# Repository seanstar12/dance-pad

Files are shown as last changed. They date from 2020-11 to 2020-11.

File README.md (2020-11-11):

DDR FSR Upgrade (https://youtu.be/kHoUUIsmSGY "DDR FSR Upgrade")

# dance-pad
Code and schematics for Dance Dance Revolution - DDR - FSR sensor upgrade.

# Plan
Use one MEGA238P per arrow to read & convert the 4 FSR values into a pressed/not-pressed signal. 
Use 25 SK6812 LEDs to light up the panel when pressed and show animations when idle.

# Parts
- Arduino-pro-mini clone
- MCP2125 - CAN - interface with Teensy
- Teensy 3.2 - interface with DDR cabinet
- SK6812 - 'Neopixel' LEDs
- FSR - x32 - 4 per tile
- ['Dance Sensor'](https://www.aliexpress.com/item/4000438156295.html) from aliexpress for the TPU shell.
- [FSR](https://www.aliexpress.com/item/4000765691363.html) from aliexpress.

# Why
I have a DDR cabinet, and I am tired of dealing with stuck sensors. This will let me 
calibrate the dance pad on the fly and never have to deal with it again. I've 
wanted to create a CANBus network for a while, and this gives me an excuse to use 
the box of pro-mini clones that I've had for a while now.

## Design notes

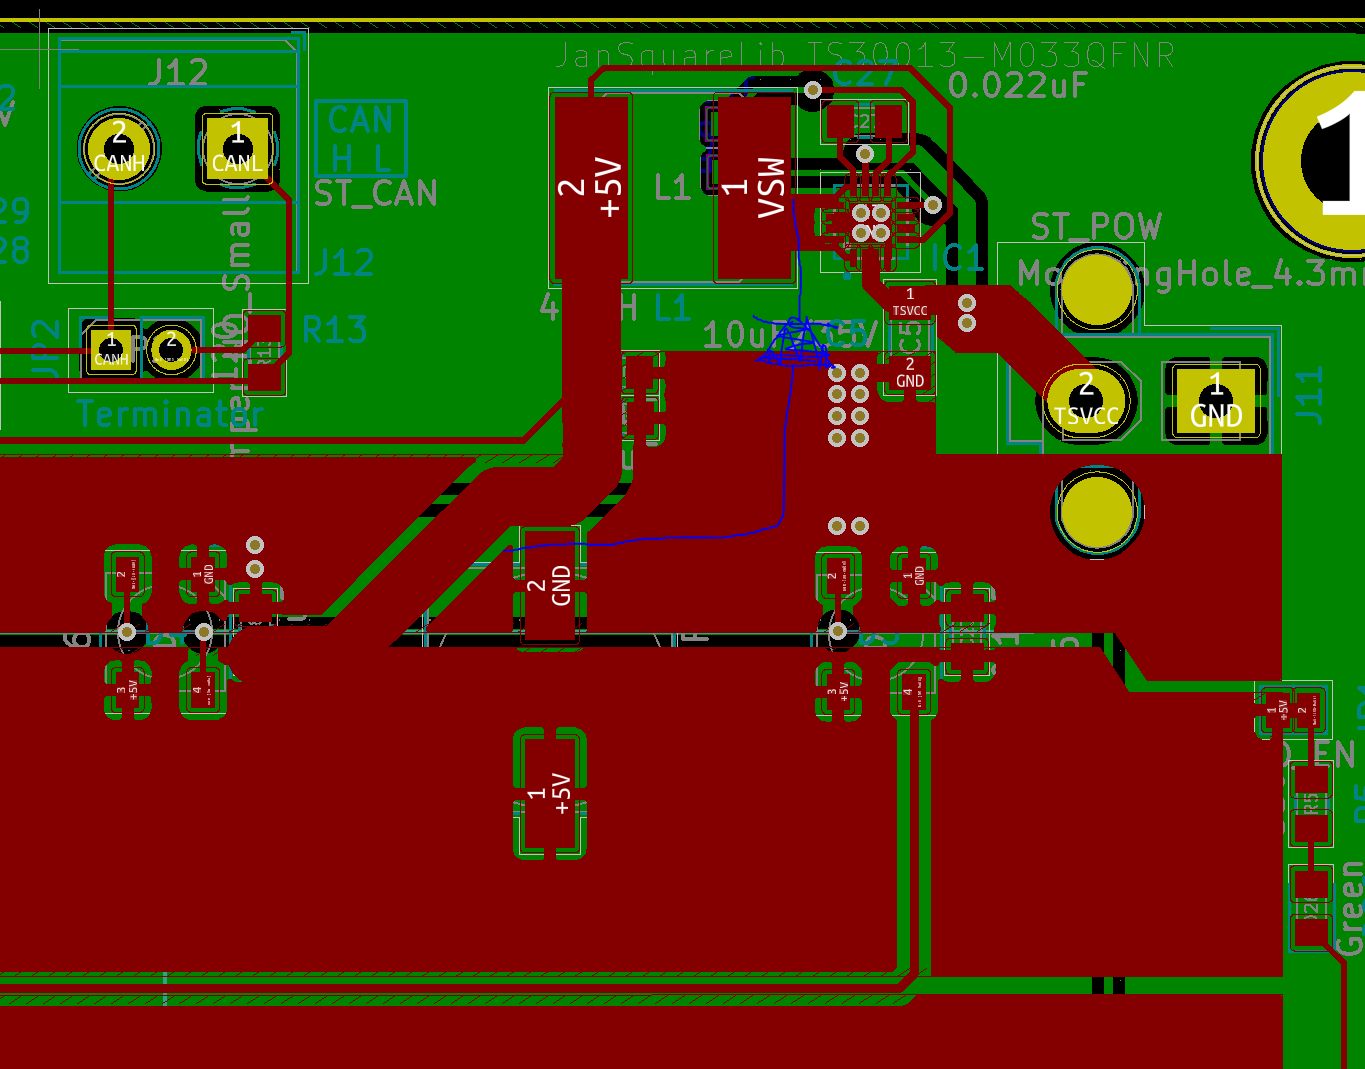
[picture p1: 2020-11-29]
ps_screenshot_diode.PNG

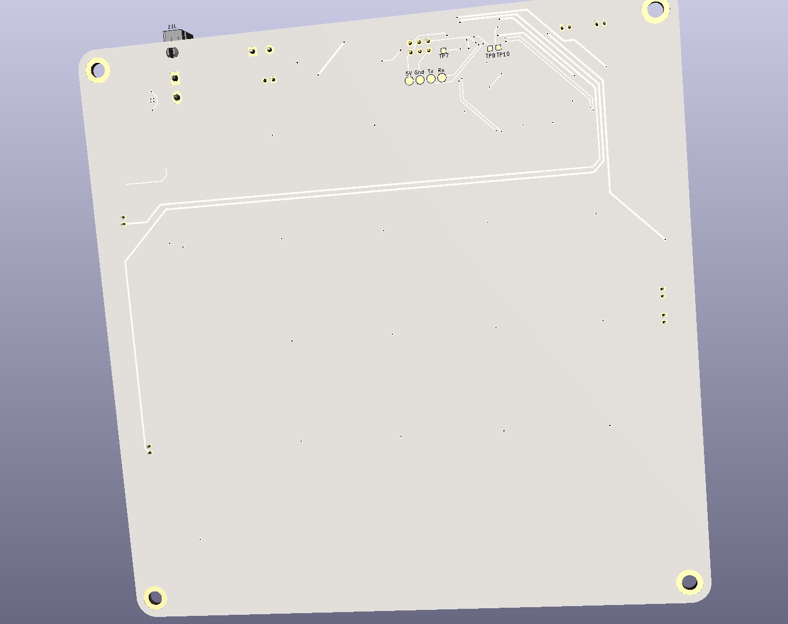
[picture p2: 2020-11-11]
Board_back.PNG

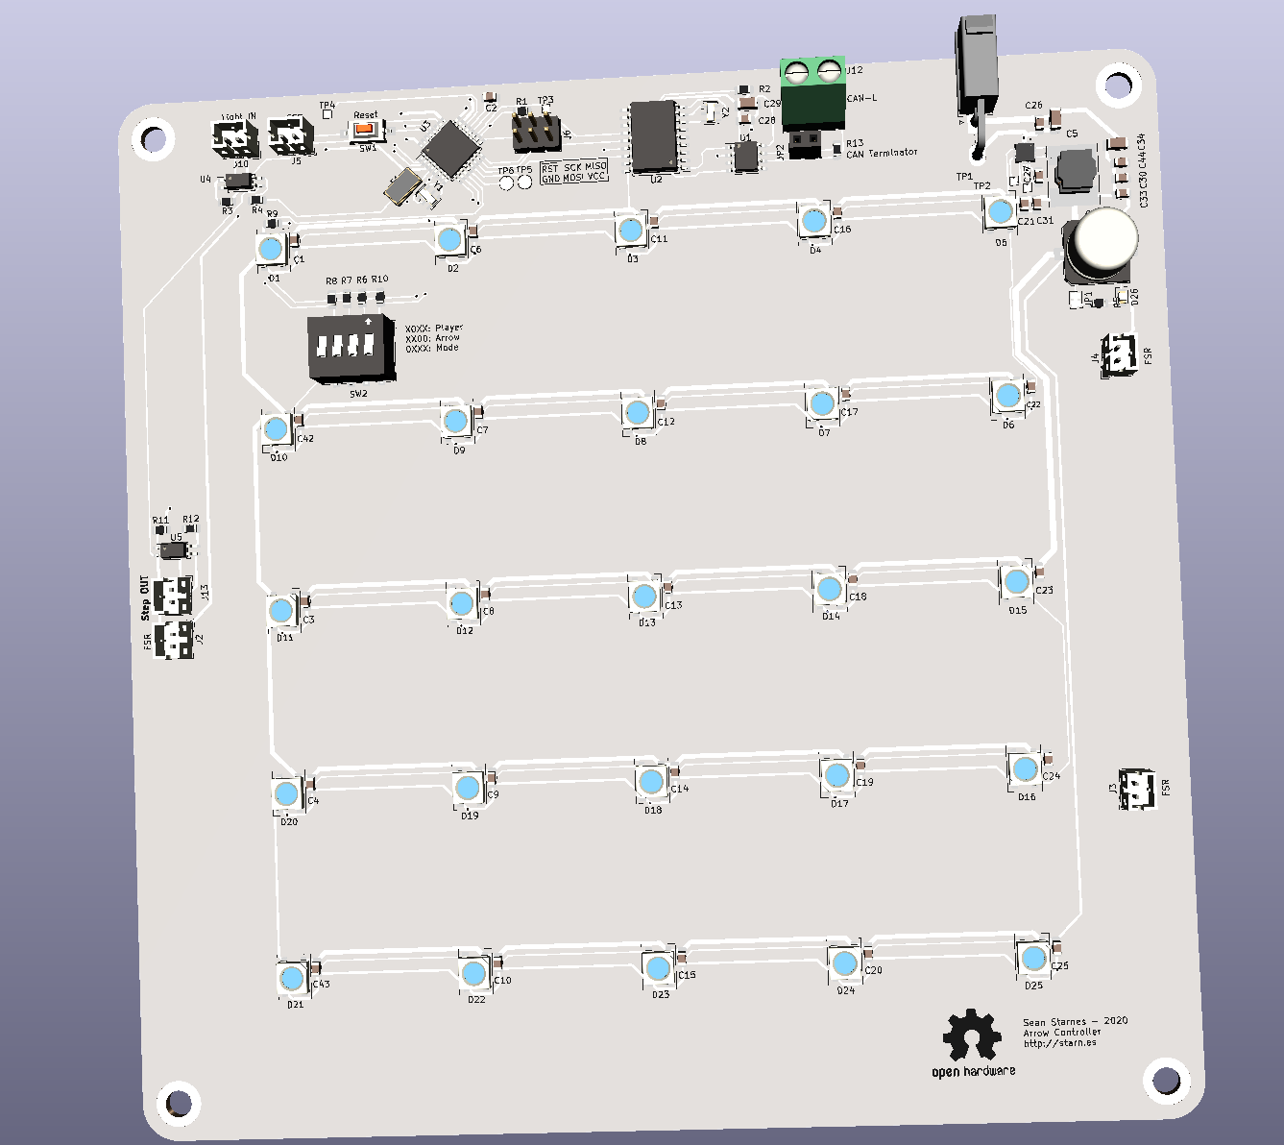
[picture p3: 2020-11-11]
Board_front.PNG

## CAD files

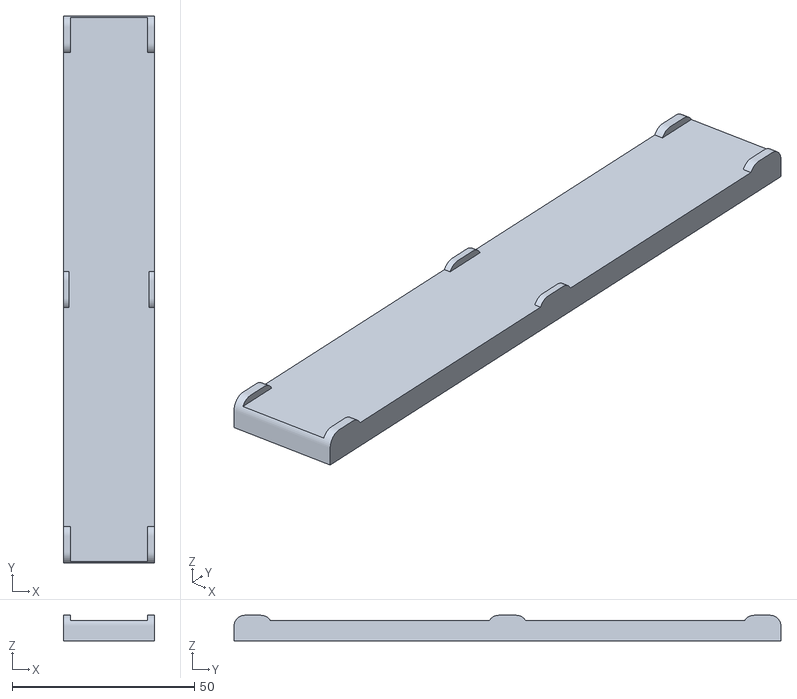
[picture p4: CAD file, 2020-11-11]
3D-prints/ddr_spacer_v3.stl
25.0 x 150.0 x 7.00

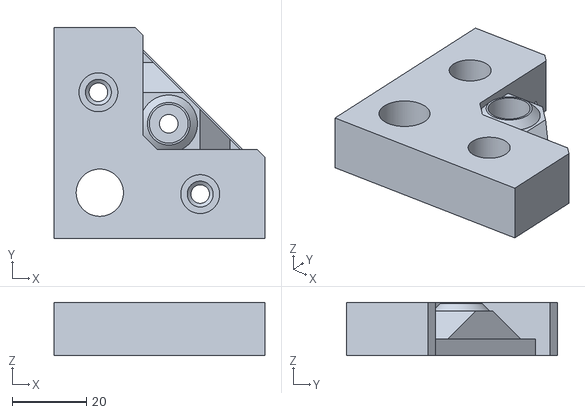
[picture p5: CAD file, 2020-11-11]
3D-prints/ddr_spacer_block.stl
57.0 x 57.0 x 14.4

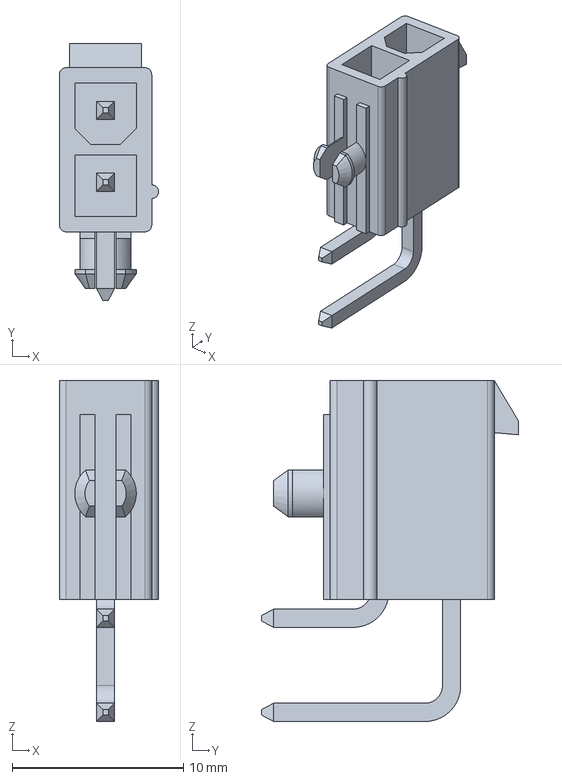
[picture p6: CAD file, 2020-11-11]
kicad/models/26-01-3114_stp/026013114.stp
5.80 x 15.0 x 19.9 mm

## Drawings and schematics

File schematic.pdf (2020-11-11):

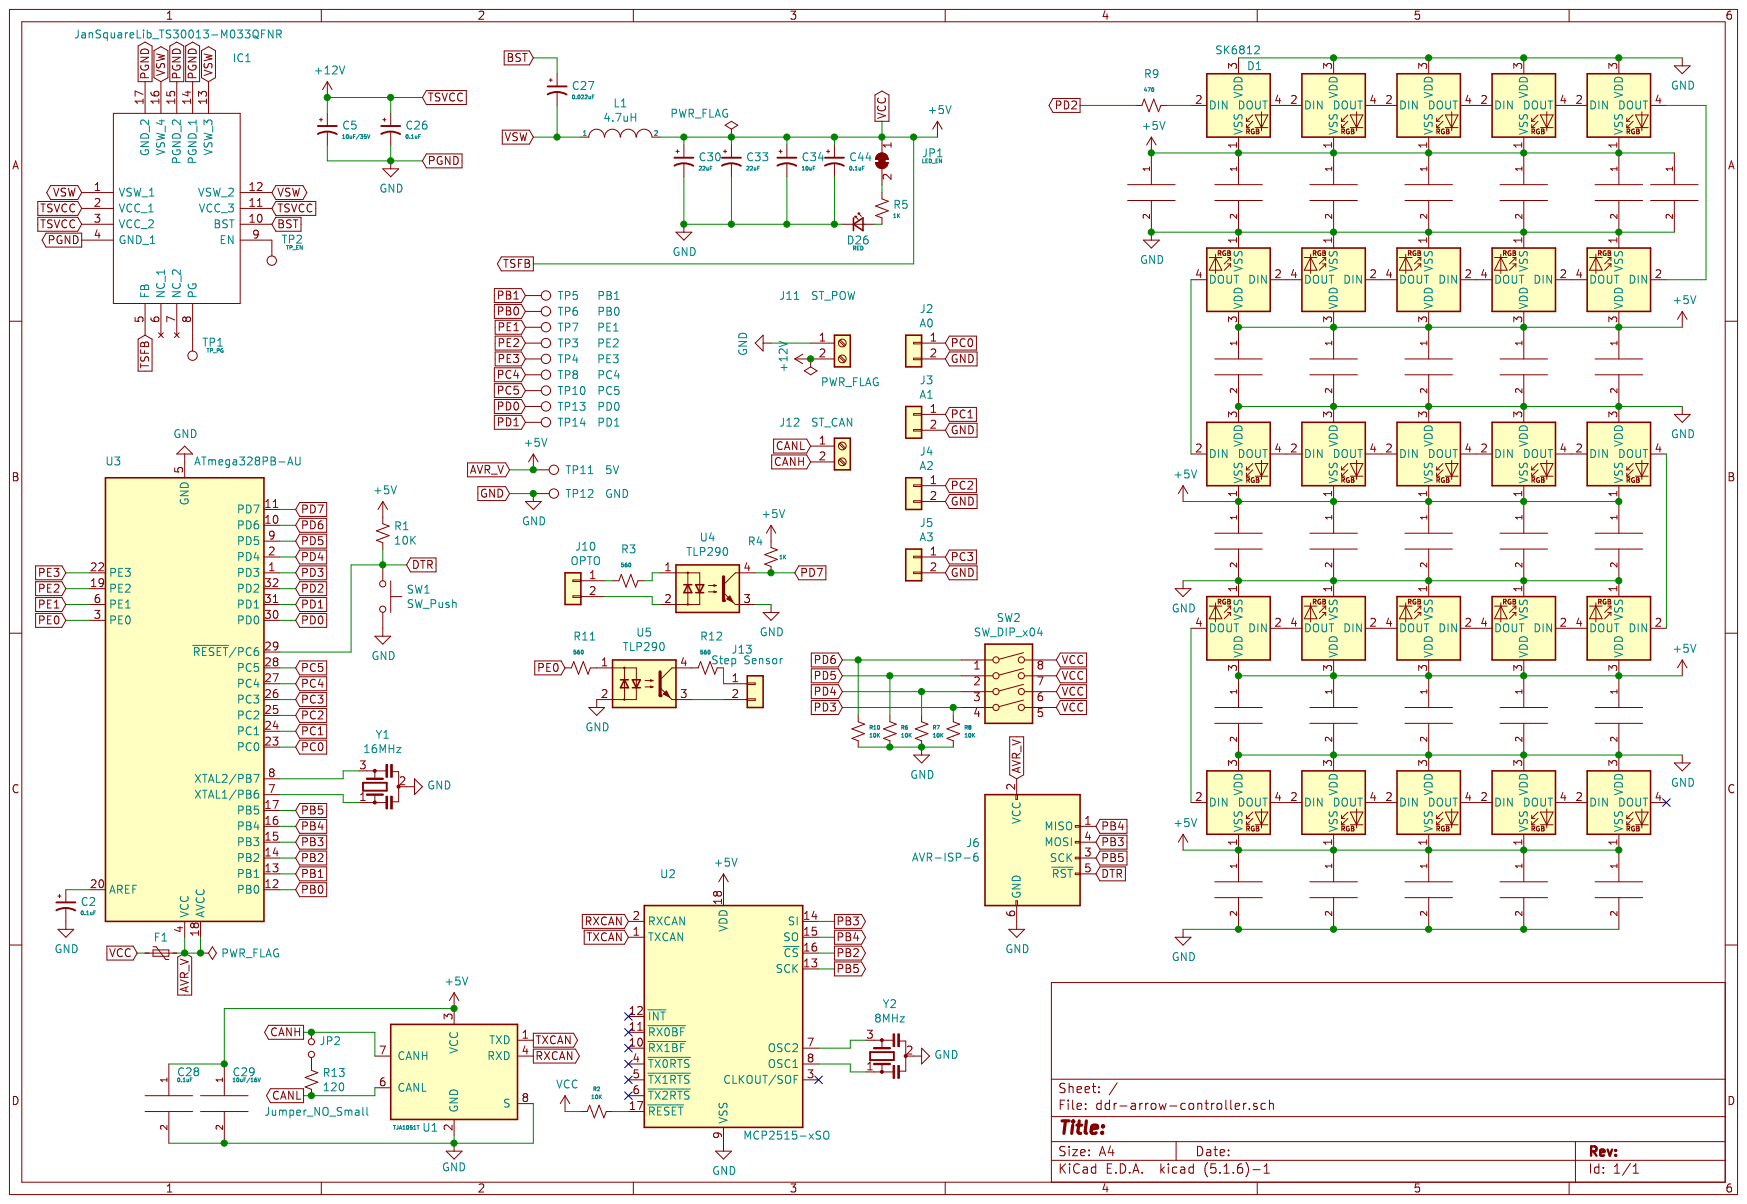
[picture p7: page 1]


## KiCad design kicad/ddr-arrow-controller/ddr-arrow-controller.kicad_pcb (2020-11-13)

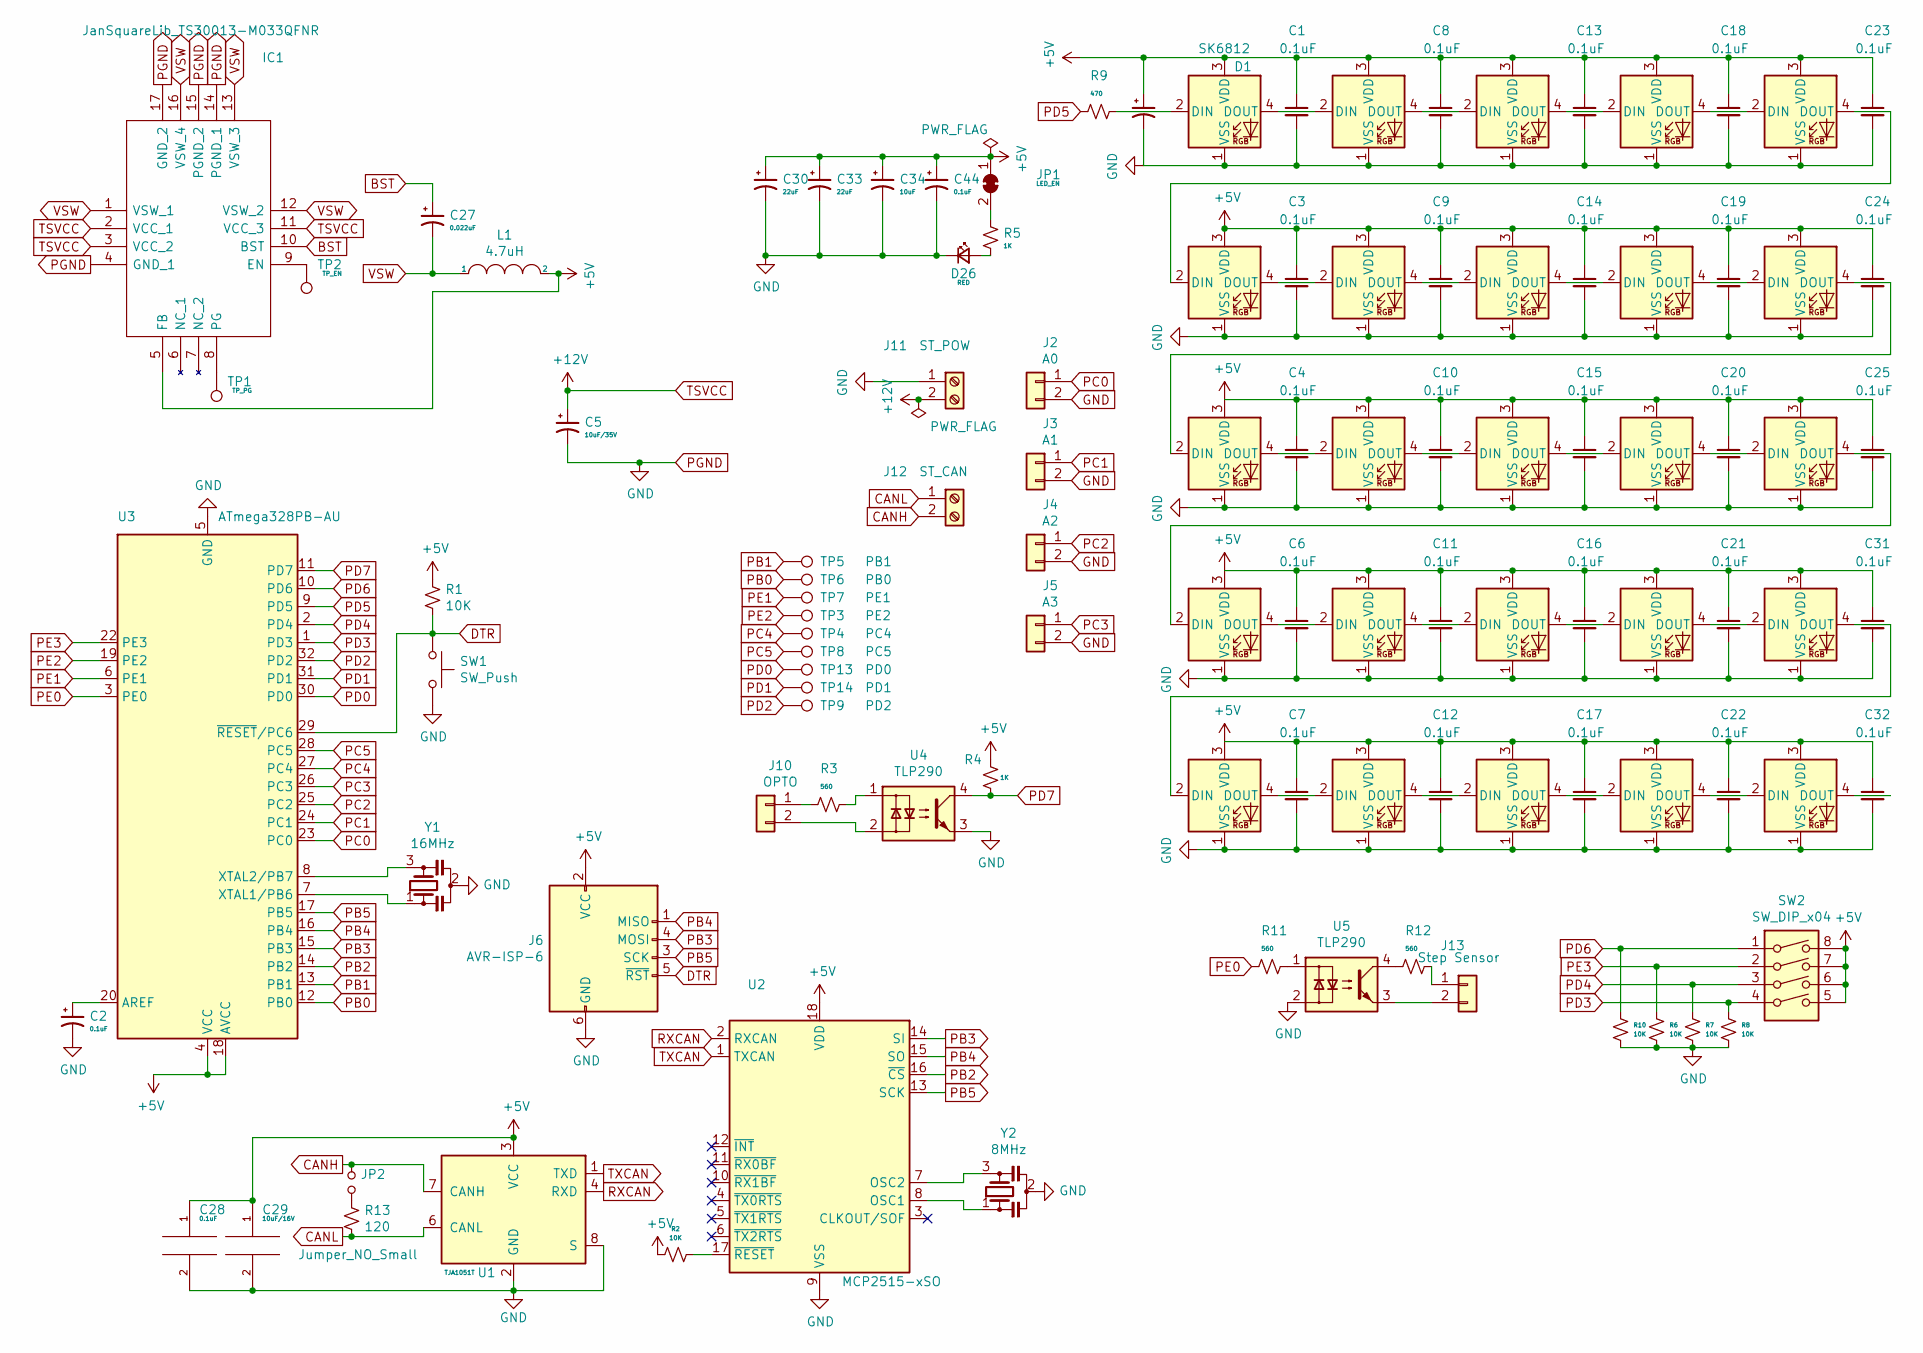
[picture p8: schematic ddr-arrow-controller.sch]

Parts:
C1, C2, C3, C4, C6, C7, C8, C9, C10, C11, C12, C13, C14, C15, C16, C17, C18, C19, C20, C21, C22, C23, C24, C25, C28, C31, C32, C44: 0.1uF; C_0805_2012Metric_Pad1.15x1.40mm_HandSolder
C5: 10uF/35V; C_1206_3216Metric_Pad1.42x1.75mm_HandSolder
C27: 0.022uF; C_0805_2012Metric_Pad1.15x1.40mm_HandSolder
C29: 10uF/16V; C_1206_3216Metric_Pad1.42x1.75mm_HandSolder
C30, C33: 22uF; C_0805_2012Metric_Pad1.15x1.40mm_HandSolder
C34: 10uF; C_1206_3216Metric_Pad1.42x1.75mm_HandSolder
C35: 1000uF; C_Elec_10x10.2
D1, D2, D3, D4, D5, D6, D7, D8, D9, D10, D11, D12, D13, D14, D15, D16, D17, D18, D19, D20, D21, D22, D23, D24, D25: SK6812; LED_SK6812_PLCC4_5.0x5.0mm_P3.2mm
D26: RED; LED_0805_2012Metric
IC1: JanSquareLib_TS30013-M033QFNR; QFN50P300X300X100-17N
J2: A0; JST_PH_B2B-PH-K_1x02_P2.00mm_Vertical
J3: A1; JST_PH_B2B-PH-K_1x02_P2.00mm_Vertical
J4: A2; JST_PH_B2B-PH-K_1x02_P2.00mm_Vertical
J5: A3; JST_PH_B2B-PH-K_1x02_P2.00mm_Vertical
J6: AVR-ISP-6; PinHeader_2x03_P2.54mm_Vertical
J10: OPTO; JST_PH_B2B-PH-K_1x02_P2.00mm_Vertical
J11: ST_POW; Molex_Mini-Fit_Jr_5569-02A2_2x01_P4.20mm_Horizontal
J12: ST_CAN; TerminalBlock_Phoenix_MKDS-1,5-2_1x02_P5.00mm_Horizontal
J13: Step Sensor; JST_PH_B2B-PH-K_1x02_P2.00mm_Vertical
JP1: LED_EN; SolderJumper-2_P1.3mm_Bridged_Pad1.0x1.5mm
JP2: Jumper_NO_Small; PinSocket_1x02_P2.54mm_Vertical
L1: 4.7uH; L_Taiyo-Yuden_NR-80xx_HandSoldering
R1, R2, R6, R7, R8, R10: 10K; R_0805_2012Metric_Pad1.15x1.40mm_HandSolder
R3, R11, R12: 560; R_0805_2012Metric_Pad1.15x1.40mm_HandSolder
R4, R5: 1K; R_0805_2012Metric_Pad1.15x1.40mm_HandSolder
R9: 470; R_0805_2012Metric_Pad1.15x1.40mm_HandSolder
R13: 120; R_0805_2012Metric_Pad1.15x1.40mm_HandSolder
SW1: SW_Push; SW_SPST_CK_RS282G05A3
SW2: SW_DIP_x04; SW_DIP_SPSTx04_Slide_9.78x12.34mm_W8.61mm_P2.54mm
TP1: TP_PG; TestPoint_Pad_1.0x1.0mm
TP2: TP_EN; TestPoint_Pad_1.0x1.0mm
TP3: PE2; TestPoint_Pad_1.0x1.0mm
TP4: PC4; TestPoint_Pad_1.0x1.0mm
TP5: PB1; TestPoint_Pad_D2.0mm
TP6: PB0; TestPoint_Pad_D2.0mm
TP7: PE1; TestPoint_Pad_1.0x1.0mm
TP8: PC5; TestPoint_Pad_1.0x1.0mm
TP9: PD2; TestPoint_Pad_D1.0mm
TP13: PD0; TestPoint_Pad_D1.0mm
TP14: PD1; TestPoint_Pad_D1.0mm
U1: TJA1051T; SOIC-8_3.9x4.9mm_P1.27mm
U2: MCP2515-xSO; SOIC-18W_7.5x11.6mm_P1.27mm
U3: ATmega328PB-AU; TQFP-32_7x7mm_P0.8mm
U4, U5: TLP290; SOP-4_4.4x2.6mm_P1.27mm
Y1: 16MHz; Resonator_SMD_muRata_CSTxExxV-3Pin_3.0x1.1mm_HandSoldering
Y2: 8MHz; Resonator_SMD_muRata_CSTxExxV-3Pin_3.0x1.1mm_HandSoldering

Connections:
+5V: C1.1, C3.1, C4.1, C6.1, C7.1, C8.1, C9.1, C10.1, C11.1, C12.1, C13.1, C14.1, C15.1, C16.1, C17.1, C18.1, C19.1, C20.1, C21.1, C22.1, C23.1, C24.1, C25.1, C28.1, C29.1, C30.1, C31.1, C32.1, C33.1, C34.1, C35.1, C44.1, D1.3 (VDD), D2.3 (VDD), D3.3 (VDD), D4.3 (VDD), D5.3 (VDD), D6.3 (VDD), D7.3 (VDD), D8.3 (VDD), D9.3 (VDD), D10.3 (VDD), D11.3 (VDD), D12.3 (VDD), D13.3 (VDD), D14.3 (VDD), D15.3 (VDD), D16.3 (VDD), D17.3 (VDD), D18.3 (VDD), D19.3 (VDD), D20.3 (VDD), D21.3 (VDD), D22.3 (VDD), D23.3 (VDD), D24.3 (VDD), D25.3 (VDD), IC1.5 (FB), J6.2 (VCC), JP1.1 (A), L1.2, R1.1, R2.2, R4.1, SW2.5, SW2.6, SW2.7, SW2.8, U1.3 (VCC), U2.18 (VDD), U3.4 (VCC), U3.18 (AVCC)
BST: C27.1, IC1.10 (BST)
CANH: J12.2, JP2.1, U1.7 (CANH)
CANL: J12.1, R13.2, U1.6 (CANL)
DTR: J6.5 (~RST), R1.2, SW1.1, U3.29 (~RESET~/PC6)
GND: C1.2, C2.2, C3.2, C4.2, C5.2, C6.2, C7.2, C8.2, C9.2, C10.2, C11.2, C12.2, C13.2, C14.2, C15.2, C16.2, C17.2, C18.2, C19.2, C20.2, C21.2, C22.2, C23.2, C24.2, C25.2, C28.2, C29.2, C30.2, C31.2, C32.2, C33.2, C34.2, C35.2, C44.2, D1.1 (VSS), D2.1 (VSS), D3.1 (VSS), D4.1 (VSS), D5.1 (VSS), D6.1 (VSS), D7.1 (VSS), D8.1 (VSS), D9.1 (VSS), D10.1 (VSS), D11.1 (VSS), D12.1 (VSS), D13.1 (VSS), D14.1 (VSS), D15.1 (VSS), D16.1 (VSS), D17.1 (VSS), D18.1 (VSS), D19.1 (VSS), D20.1 (VSS), D21.1 (VSS), D22.1 (VSS), D23.1 (VSS), D24.1 (VSS), D25.1 (VSS), D26.1 (K), IC1.4 (GND_1), IC1.14 (PGND_1), IC1.15 (PGND_2), IC1.17 (GND_2), J2.2, J3.2, J4.2, J5.2, J6.6 (GND), J11.1, R6.2, R7.2, R8.2, R10.2, SW1.2, U1.2 (GND), U1.8 (S), U2.9 (VSS), U3.5 (GND), U3.21 (GND), U4.3, U5.2, Y1.2, Y2.2
unnamed: C2.1, U3.20 (AREF)
unnamed: D1.2 (DIN), R9.1
unnamed: D1.4 (DOUT), D2.2 (DIN)
unnamed: D2.4 (DOUT), D3.2 (DIN)
unnamed: D3.4 (DOUT), D4.2 (DIN)
unnamed: D4.4 (DOUT), D5.2 (DIN)
unnamed: D5.4 (DOUT), D6.2 (DIN)
unnamed: D6.4 (DOUT), D7.2 (DIN)
unnamed: D7.4 (DOUT), D8.2 (DIN)
unnamed: D8.4 (DOUT), D9.2 (DIN)
unnamed: D9.4 (DOUT), D10.2 (DIN)
unnamed: D10.4 (DOUT), D11.2 (DIN)
unnamed: D11.4 (DOUT), D12.2 (DIN)
unnamed: D12.4 (DOUT), D13.2 (DIN)
unnamed: D13.4 (DOUT), D14.2 (DIN)
unnamed: D14.4 (DOUT), D15.2 (DIN)
unnamed: D15.4 (DOUT), D16.2 (DIN)
unnamed: D16.4 (DOUT), D17.2 (DIN)
unnamed: D17.4 (DOUT), D18.2 (DIN)
unnamed: D18.4 (DOUT), D19.2 (DIN)
unnamed: D19.4 (DOUT), D20.2 (DIN)
unnamed: D20.4 (DOUT), D21.2 (DIN)
unnamed: D21.4 (DOUT), D22.2 (DIN)
unnamed: D22.4 (DOUT), D23.2 (DIN)
unnamed: D23.4 (DOUT), D24.2 (DIN)
unnamed: D24.4 (DOUT), D25.2 (DIN)
unnamed: D26.2 (A), R5.2
unnamed: IC1.8 (PG), TP1.1
unnamed: IC1.9 (EN), TP2.1
unnamed: J10.1, R3.2
unnamed: J10.2, U4.2
unnamed: J13.1, R12.1
unnamed: J13.2, U5.3
unnamed: JP1.2 (B), R5.1
unnamed: JP2.2, R13.1
unnamed: R2.1, U2.17 (~RESET)
unnamed: R3.1, U4.1
unnamed: R11.1, U5.1
unnamed: R12.2, U5.4
unnamed: U2.7 (OSC2), Y2.3
unnamed: U2.8 (OSC1), Y2.1
unnamed: U3.7 (XTAL1/PB6), Y1.1
unnamed: U3.8 (XTAL2/PB7), Y1.3
PB0: TP6.1, U3.12 (PB0)
PB1: TP5.1, U3.13 (PB1)
PB2: U2.16 (~CS), U3.14 (PB2)
PB3: J6.4 (MOSI), U2.14 (SI), U3.15 (PB3)
PB4: J6.1 (MISO), U2.15 (SO), U3.16 (PB4)
PB5: J6.3 (SCK), U2.13 (SCK), U3.17 (PB5)
PC0: J2.1, U3.23 (PC0)
PC1: J3.1, U3.24 (PC1)
PC2: J4.1, U3.25 (PC2)
PC3: J5.1, U3.26 (PC3)
PC4: TP4.1, U3.27 (PC4)
PC5: TP8.1, U3.28 (PC5)
PD0: TP13.1, U3.30 (PD0)
PD1: TP14.1, U3.31 (PD1)
PD2: TP9.1, U3.32 (PD2)
PD3: R8.1, SW2.4, U3.1 (PD3)
PD4: R7.1, SW2.3, U3.2 (PD4)
PD5: R9.2, U3.9 (PD5)
PD6: R10.1, SW2.1, U3.10 (PD6)
PD7: R4.2, U3.11 (PD7), U4.4
PE0: R11.2, U3.3 (PE0)
PE1: TP7.1, U3.6 (PE1)
PE2: TP3.1, U3.19 (PE2)
PE3: R6.1, SW2.2, U3.22 (PE3)
RXCAN: U1.4 (RXD), U2.2 (RXCAN)
TSVCC: C5.1, IC1.2 (VCC_1), IC1.3 (VCC_2), IC1.11 (VCC_3), J11.2
TXCAN: U1.1 (TXD), U2.1 (TXCAN)
VSW: C27.2, IC1.1 (VSW_1), IC1.12 (VSW_2), IC1.13 (VSW_3), IC1.16 (VSW_4), L1.1

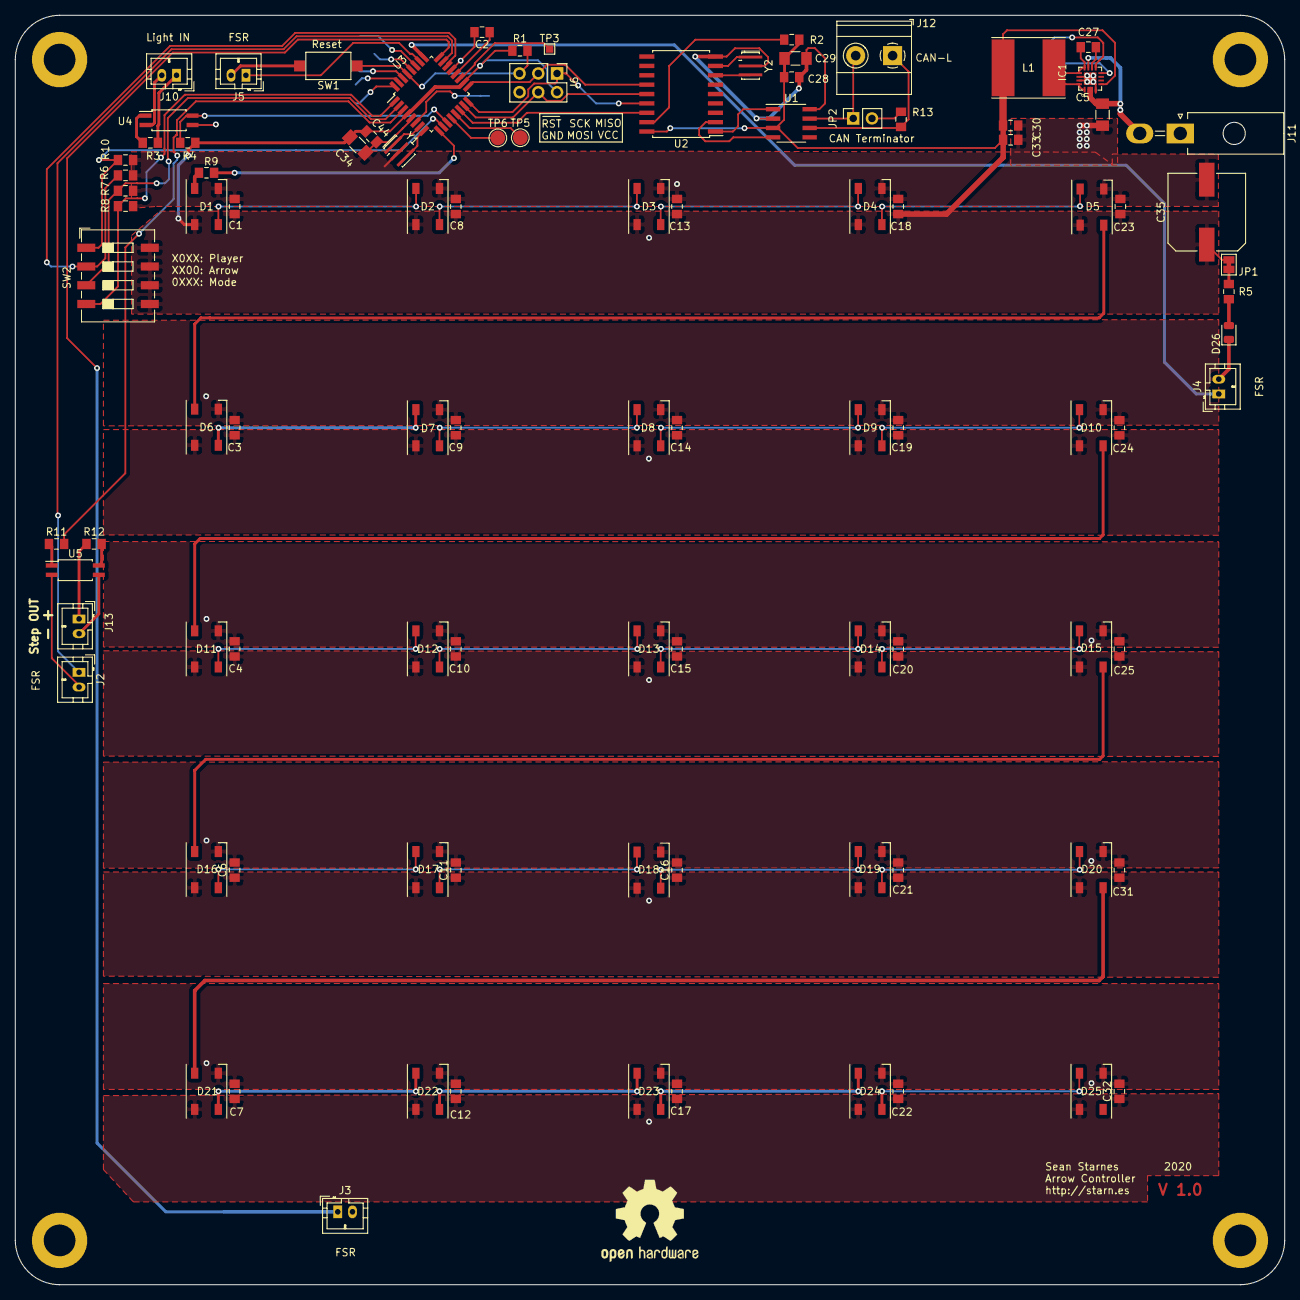
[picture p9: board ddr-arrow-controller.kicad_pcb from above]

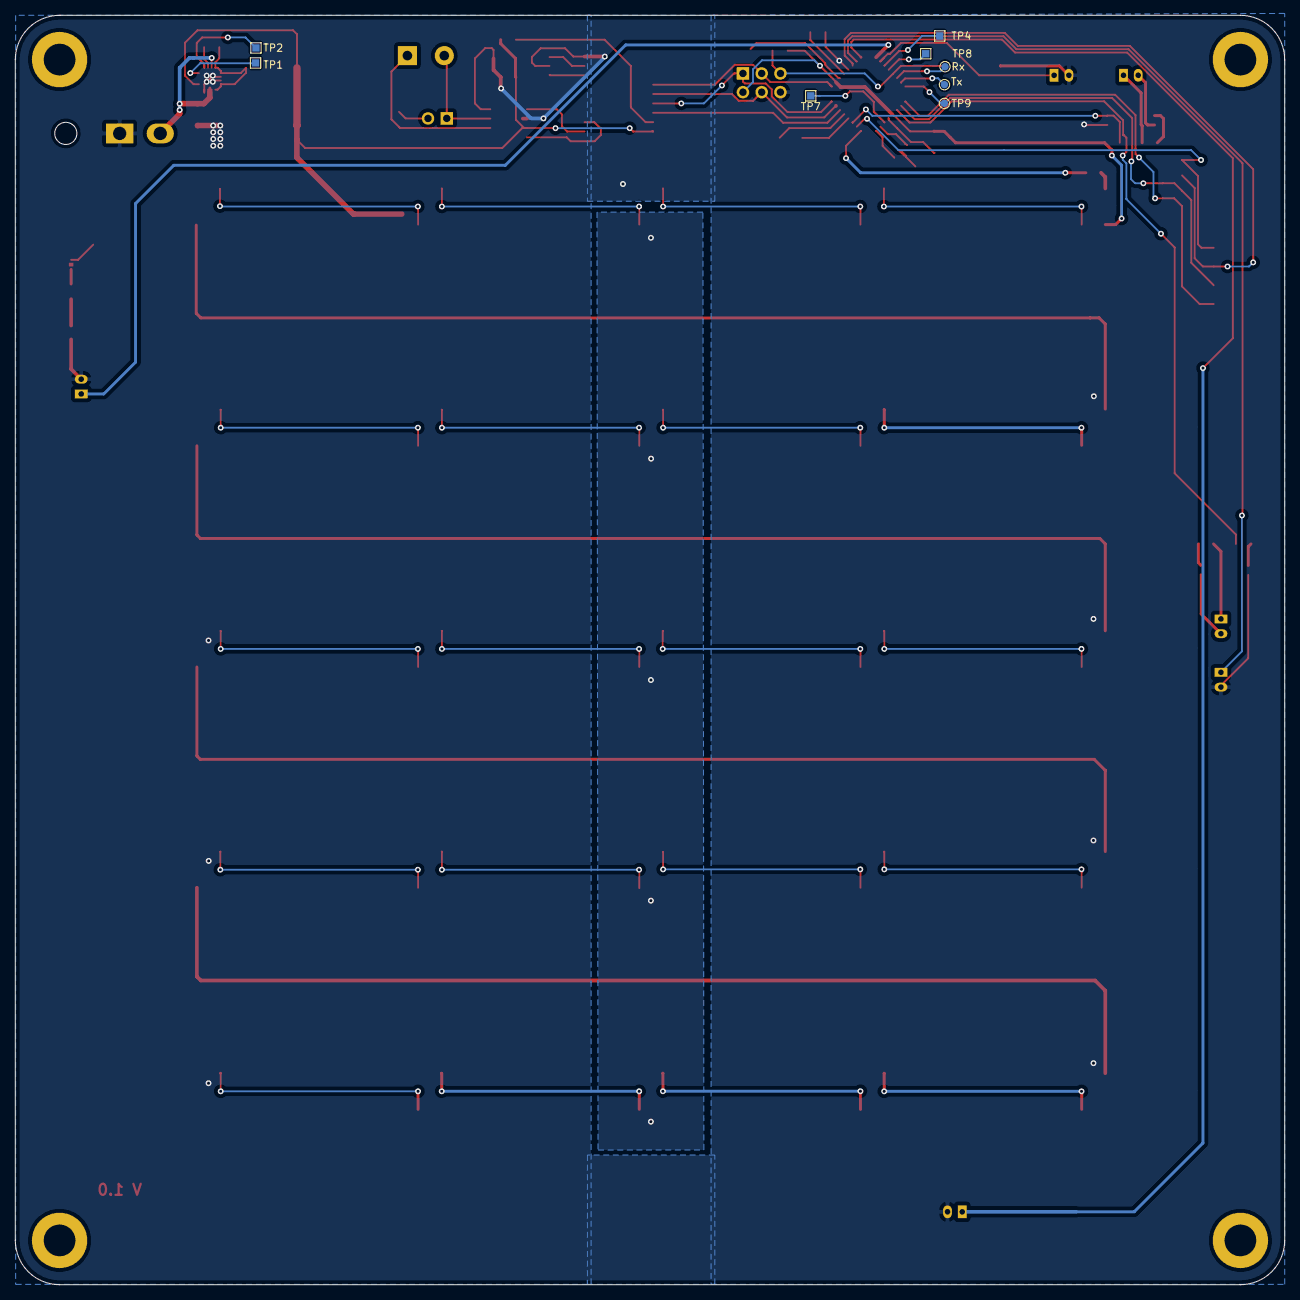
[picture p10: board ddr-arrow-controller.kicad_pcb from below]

Board: 2 copper layers, 172.0 x 172.0 mm, 107 parts (8 on the bottom side), 77 nets.

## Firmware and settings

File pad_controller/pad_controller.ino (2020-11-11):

//#include <Streaming.h>
#include <avdweb_AnalogReadFast.h>
#include <Adafruit_NeoPixel.h>
#include <CAN.h>

template <typename T, size_t N> constexpr size_t array_size(const T (&)[N]) { return N; }

uint8_t adcPins[] = {A0, A1, A2, A3};
uint8_t idntPins[] = {9, 8, 7};
float adcValues[] = {0.0, 0.0, 0.0, 0.0};
float adcBaseValues[] = {0.0, 0.0, 0.0, 0.0};
String arrows[] = {"Left", "Down", "Right", "Up"};
String _arrows[] = {"L", "D", "R", "U"};
int prevActive = 0;

char data_pad = 0;     // B0 - player_1; B1 - player_2
char data_arrow = 0;   // B0 - left; B1 - down; B10 - right; B11 - up;
char data_pressed = 0; // B0 - off; B1 - on;

#define LED_PIN 2
#define LED_COUNT 5
#define AVG 20

Adafruit_NeoPixel strip(LED_COUNT, LED_PIN, NEO_RGB + NEO_KHZ800);

float readAnalogPin(uint8_t pin) {
  float adc = 0;
  int count = 0;

  while(count < AVG) {
    adc += analogReadFast(pin);
    count++;
  }

  return (adc / AVG);
}

void readAnalogPins(uint8_t pin[], int sizeOfArray) {
 
  for (int k = 0; k < sizeOfArray; k++) {
    float adc = 0;
    int count = 0;
    
    adcValues[k] = readAnalogPin(pin[k]);
  }

  // test statements
  if (false) {
    Serial.print(adcValues[0]);
    Serial.print("\t");
    Serial.print(adcValues[1]);
    Serial.print("\t");
    Serial.print(adcValues[1]);
    Serial.print("\n");
  }
}


void setup(void) { 
  Serial.begin(115200);
  // init neopixels 
  strip.begin();
  strip.show();

  // set pullups for adc sensors
  for (int i = 0; i < 4; i++) {
    pinMode(adcPins[i], INPUT_PULLUP);
  }

  // set pullups for identity pins
  for (int m = 0; m < 3; m++) {
    pinMode(idntPins[m], INPUT_PULLUP);
  }


  // Read identity pins for config
  // left, down, up, right
  data_pad = digitalRead(9) == HIGH ? 1 : 0;
  data_pad += digitalRead(7) == HIGH ? 2 : 0;
  data_pad += digitalRead(8) == HIGH ? 4 : 0;
  
  // take AVG readings
  for (int k = 0; k < AVG; k++) {
    readAnalogPins(adcPins, 4);

    // read each sensor
    for (int j = 0; j < 4; j++) {
      adcBaseValues[j] += adcValues[j];
    }
  }

  // average each sensor
  for (int l = 0; l < 4; l++) {
    adcBaseValues[l] = (adcBaseValues[l] / AVG);
  }

  if (false){
    Serial.print("Base Values: ");
    Serial.print(adcBaseValues[0]);
    Serial.print("\t");
    Serial.println(adcBaseValues[1]);
    delay(200);
  }

  if (true) {
  Serial.print("Player: ");
  Serial.print(bitRead(data_pad, 0) + 1, HEX);
  Serial.print("\t Arrow: ");
  Serial.println(_arrows[data_pad >> 1]);
  //Serial.print("\t");
  //Serial.print("Arrow");

  }
  
  if (!CAN.begin(500000)) {
    Serial.println("Starting CAN failed!");
    while (1);
  }
}

void loop(void) {
  int active = 0;
  
  readAnalogPins(adcPins, 4);

  // if 25% change in value, trigger 'sensor pressed'
  for (int i = 0; i < 4; i++) {
    if ((adcBaseValues[i] - adcBaseValues[i]*0.25) > adcValues[i]) {
      active++;
    }
  }

  //set green pixel if any sensor is triggered (debug)
  if (active > 0) {
    strip.setPixelColor(4, 60, 0, 0);
  }
  else {
    strip.setPixelColor(4, 0, 0, 0);
  }

  // send change over CANBus 
  if (active != prevActive) {
    CAN.beginPacket(0x12);
    CAN.write(bitRead(data_pad, 0));
    CAN.write(data_pad >> 1);
    CAN.write((active > 0) ? 0x01 : 0x00);
    CAN.endPacket();
  }
  
  prevActive = active; 

  // set 'pressure' from sensor
  // blue if pressed, red if hard pressed.
  // @TODO remove in final, testing only
  for (int i = 0; i < 4; i++) {
    int val = 1024 - adcValues[i];
    int r = 0;
    int g = 0;
    int b = 0;

    if (val < 510) {
      b = val / 2;
    }
    else if ( val >= 510 ) {
      r = map(val - 510, 0, 512, 0, 250);
      b = (r <= 200) ? 200 - r : 0;
    }
    strip.setPixelColor(i, g, r, b);
  }

  // render neopixels 
  strip.show();

  
  if (false) {
    Serial.print(adcValues[0]);
    Serial.print("\t");
    Serial.print(adcValues[1]);
    Serial.print("\t");
    Serial.print(active);
    Serial.print("\n");
  }
}

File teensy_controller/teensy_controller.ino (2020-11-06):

#include <FlexCAN.h>
#include <Keypad.h>

static CAN_message_t msg;
int txCount,rxCount;

const unsigned int CANSpeed = 500000;

// left, down, right, up
// use j-pac defaults for player1 & player2
uint16_t _arrows[4][4] = {
  {KEY_LEFT, KEY_DOWN, KEY_RIGHT, KEY_UP},
  {'d', 'f', 'g', 'r'}
}; 

FlexCAN CANbus(CANSpeed);

static void hexDump(uint8_t dumpLen, uint8_t *bytePtr) {
  uint8_t hex[17] = "0123456789abcdef";
  uint8_t working;
  
  while (dumpLen--) {
    working = *bytePtr++;
    Serial.write(hex[working >> 4]);
    Serial.write(hex[working & 15]);
  }
  
  Serial.write('\r');
  Serial.write('\n');
}

void setup() {
  // put your setup code here, to run once:
  Serial.begin(115200);

  CANbus.begin();
  Keyboard.begin();
  
  Serial.println(F("Teensy Start"));
}


void loop() {
  // put your main code here, to run repeatedly:

  while (CANbus.available()) {
    CANbus.read(msg);
    Serial.print("BUS: "); hexDump(3, msg.buf);
    
    if (msg.buf[2] == 1) {
      //Serial.println("Pressed");
      Keyboard.press(_arrows[msg.buf[0]][msg.buf[1]]);
    }
    else {
      //Serial.println("unPressed");
      Keyboard.release(_arrows[msg.buf[0]][msg.buf[1]]);
    }

    rxCount++;
  }
  
}

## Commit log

2020-11-05 Kicad schematic WIP
    added LEDs. started modeling arduino-pro-mini clone footprint.
    [ddr-arrow-controller.kicad_pcb, ddr-arrow-controller.sch]
2020-11-06 Updated Controllers
    Updated pad & teensy controllers for CAN testing.
2020-11-06 Teensy cleanup
2020-11-07 Schematic Updates
    Placed microcontroller, CANBus chips, power regulator.
    [ddr-arrow-controller.kicad_pcb, ddr-arrow-controller.sch]
2020-11-11 Board layout v1 complete
    [026013114.stp, ddr-arrow-controller.kicad_pcb, ddr-arrow-controller.sch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]
2020-11-13 Rerouted PCB
    Fixed pcb plains. Fixed grounds. Fixed rounded pads. Exported Gerber files.
    [ddr-arrow-controller-B_Cu.gbr, ddr-arrow-controller-B_Mask.gbr, ddr-arrow-controller-B_SilkS.gbr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]
2020-11-29 Added screenshot of PS
    Add power supply screenshot of TS30013
